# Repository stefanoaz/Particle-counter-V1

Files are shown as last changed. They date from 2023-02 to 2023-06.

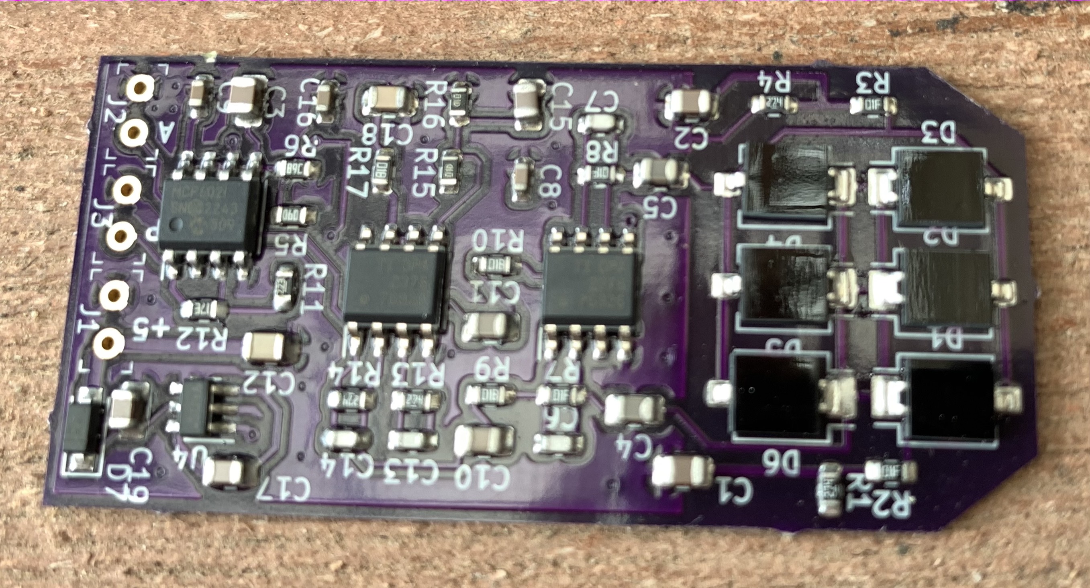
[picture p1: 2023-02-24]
IMG_3800.jpg

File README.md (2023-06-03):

# Particle-counter-V1
PIN_Diode based radiation particle counter with differential sensing

This is a beta/gamma particle detector designed with differential sensing of the PIN diode signal, to establish some rejection of common-mode EMI. Transimpedance amplifiers with high gain are very similar to an oscilloscope probe amplifier: high impedance and very sensitive to external interference. By sensing symmetrically across both sides of the diodes, common-mode rejection of 40dB can be achieved. In batches of 1% resistor and 5% capacitor tolerances, matching can be achieved of 0.1% for R and 1% for C. This will yield 40dB CMRR.

This design is intended for remote sensing for balloon flights or similar weight-sensitive applications: assembled weight is 3.3g. As such, the added weight (and difficulty) of shielding is avoided, or reduced, by incorporating common-mode rejection.

Notes:
For U1 and U3, good opamps are: OPA-2376, AD8692 or TLV2772. U2 is an MCP602.
A charge pump voltage doubler is needed to increase the reverse bias across the PIN diodes: this enlarges the diode depletion region, which is where particle detection takes place. The reverse bias makes AC coupling to the opamps necessary.

Do not exceed 5.5V Vcc.

Steve

Note 26 March 2023: There are recommended resistor value changes in the photodiode bias string. R2,3 should be lowered to 4.7 Meg., R1,4 should be lowered to 270K ohm.

Note 2 June, 2023: Recommend Version 2 of this design for improved EMI immunity and CMRR. See: "Particle-counter-V2" repository.

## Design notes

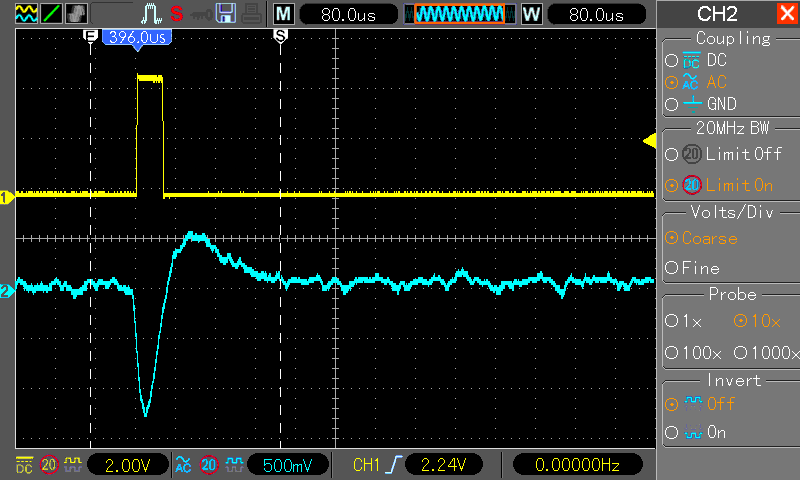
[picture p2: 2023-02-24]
hantek74_1.gif

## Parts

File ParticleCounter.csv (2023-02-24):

Id | Designator | Package | Quantity | Designation | Supplier and ref
1 | C9,C16,C8 | C_0603_1608Metric | 3 | 0.1uF
2 | R11 | R_0603_1608Metric | 1 | 22K
3 | J2,J3,J1 | PinHeader_1x2_P2.54mm | 3 | M20-9990246
4 | R2,R3,R8,R7 | R_0603_1608Metric | 4 | 10M
5 | C1,C18,C2 | C_0805_2012Metric | 3 | 0.1uF
6 | C5,C11,C10,C4 | C_0805_2012Metric | 4 | 0.047uF
7 | C17,C19 | C_0805_2012Metric | 2 | 3.3uF
8 | C12 | C_0805_2012Metric | 1 | 22uF
9 | C13,C14 | C_0603_1608Metric | 2 | 33pF
10 | R4,R1 | R_0603_1608Metric | 2 | 1M
11 | R15,R16 | R_0603_1608Metric | 2 | 100K
12 | R10,R9 | R_0603_1608Metric | 2 | 1K
13 | D2,D4,D6,D3,D5,D1 | Osram_BPW34S-SMD | 6 | BPW34-SMD
14 | R12 | R_0603_1608Metric | 1 | 1.5M
15 | U3,U1 | SO-8_3.9x4.9mm_P1.27mm | 2 | TLV2772
16 | R13,R14 | R_0603_1608Metric | 2 | 270K
17 | C6,C7 | C_0603_1608Metric | 2 | 4.7pF
18 | R17 | R_0603_1608Metric | 1 | 100
19 | R6 | R_0603_1608Metric | 1 | 82K
20 | C15 | C_0805_2012Metric | 1 | 4.7uF
21 | U4 | SOT-23-6 | 1 | LM2665M6
22 | C3 | C_0805_2012Metric | 1 | 1uF
23 | R5 | R_0603_1608Metric | 1 | 120K
24 | U2 | SO-8_3.9x4.9mm_P1.27mm | 1 | MCP602
25 | D7 | D_SOD-123 | 1 | MBR0520

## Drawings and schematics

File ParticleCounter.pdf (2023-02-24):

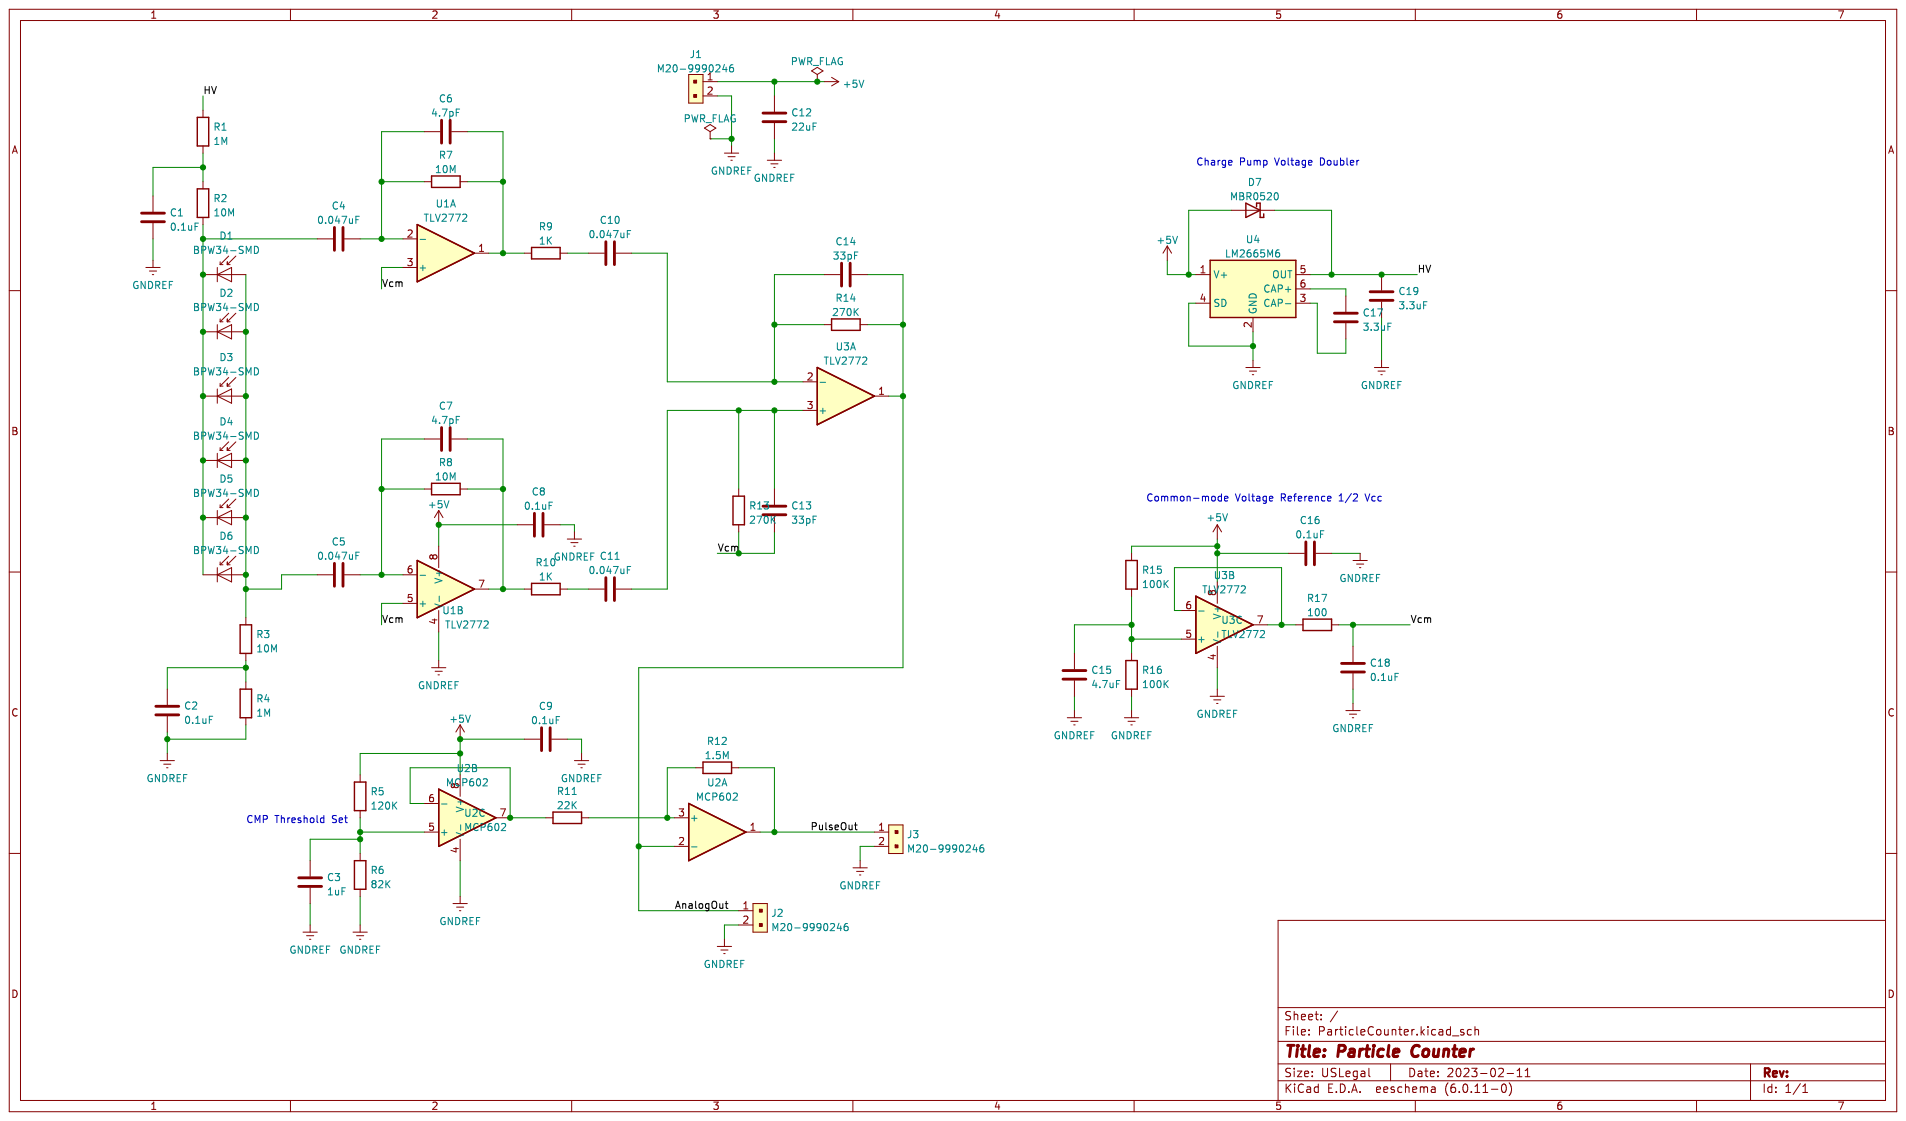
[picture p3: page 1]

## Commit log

2023-02-24 Add files via upload
    PCB gerber files
2023-02-24 Add files via upload
    PArticle counter KiCAD schematic
    [ParticleCounter.kicad_sch]
2023-02-24 Add files via upload
    Schematic PDF
2023-02-24 Add files via upload
    BOM
    [ParticleCounter.csv]
2023-02-24 Add files via upload
    Assembled PCB photo
2023-02-24 Add files via upload
    Particle Counter schematic PDF
2023-02-24 Add files via upload
    Oscilloscope trace, particle detection
